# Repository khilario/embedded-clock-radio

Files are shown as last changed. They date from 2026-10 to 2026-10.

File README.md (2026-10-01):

# Embedded Clock Radio

A custom embedded clock radio built around the Raspberry Pi Pico W, featuring FM radio playback, alarm functionality, an OLED user interface, rotary encoder controls, a custom 4-layer PCB, and a 3D-printed enclosure.

This project was completed for **ECE 299 at the University of Victoria** as a two-person engineering design project.

<p align="center">
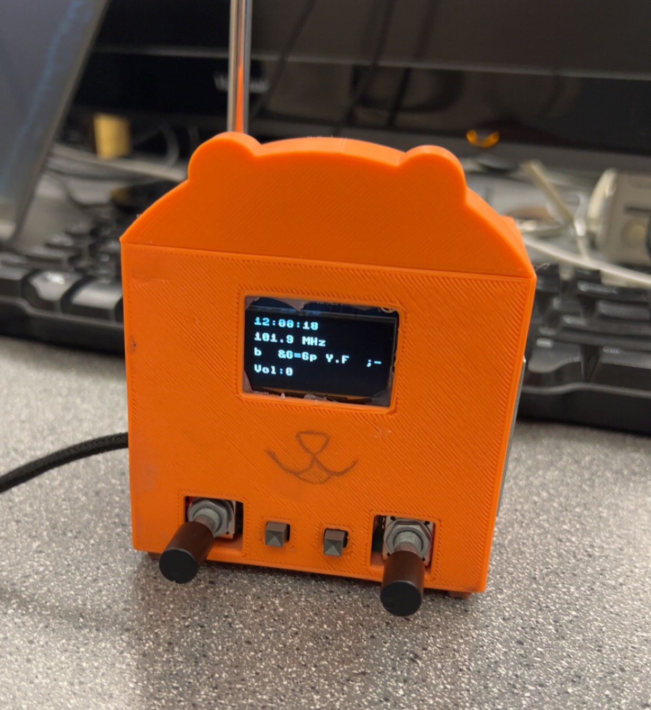
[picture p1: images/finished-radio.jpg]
Finished Embedded Clock Radio
  
</p>

## Project Overview

The goal of this project was to design and build a fully integrated clock radio using a Raspberry Pi Pico W running MicroPython.

The system combines embedded firmware, analog audio circuitry, PCB design, user-interface development, and mechanical enclosure design into a single working device.

### Key Features

- FM radio tuning and playback
- 12-hour and 24-hour time display
- Configurable alarm functionality
- Snooze and alarm cancellation
- OLED user interface
- Rotary encoder control for volume and radio tuning
- RDS station and track information
- Custom 4-layer PCB
- LM386-based audio amplification
- Custom 3D-printed enclosure

## Hardware

The clock radio is built around the following components:

- Raspberry Pi Pico W (RP2040)
- RDA5807M FM radio receiver
- SSD1306 1.3" OLED display
- LM386 audio amplifier
- 2 W, 8 Ω speaker
- 2 rotary encoders
- Push buttons
- Custom 4-layer PCB

## Communication Interfaces

- **I²C** — communication with the RDA5807M FM receiver
- **SPI** — communication with the SSD1306 OLED display
- **GPIO** — rotary encoders and push-button inputs

## PCB Design

The PCB was designed in **KiCad** as a compact 4-layer board.

The design separated power, ground, digital control, and analog audio signals across multiple layers to improve routing and reduce interference.

The board was fabricated externally and manually assembled using both SMD and through-hole components.

### PCB

<p align="center">
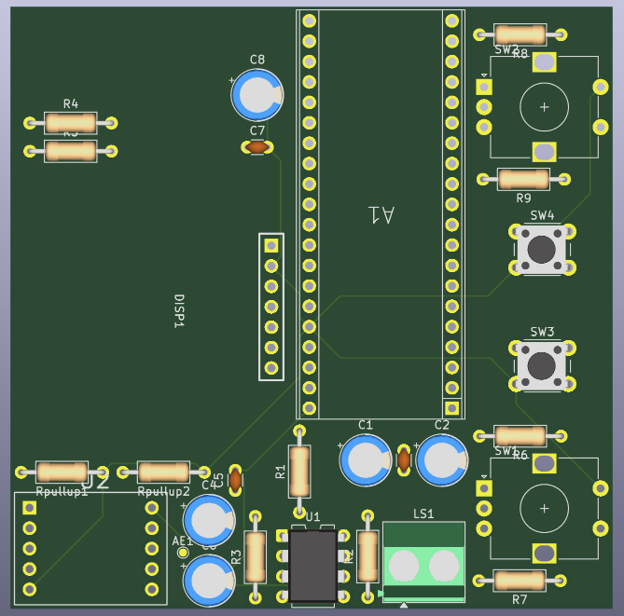
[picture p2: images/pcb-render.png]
KiCad PCB 3D Render
  
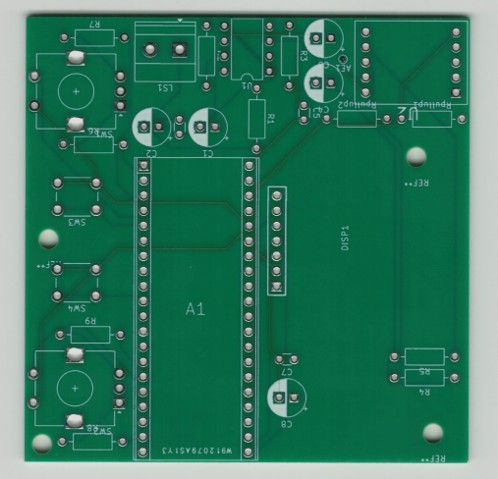
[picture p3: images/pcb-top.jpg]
Fabricated PCB
  
</p>

### Circuit Schematic

<p align="center">
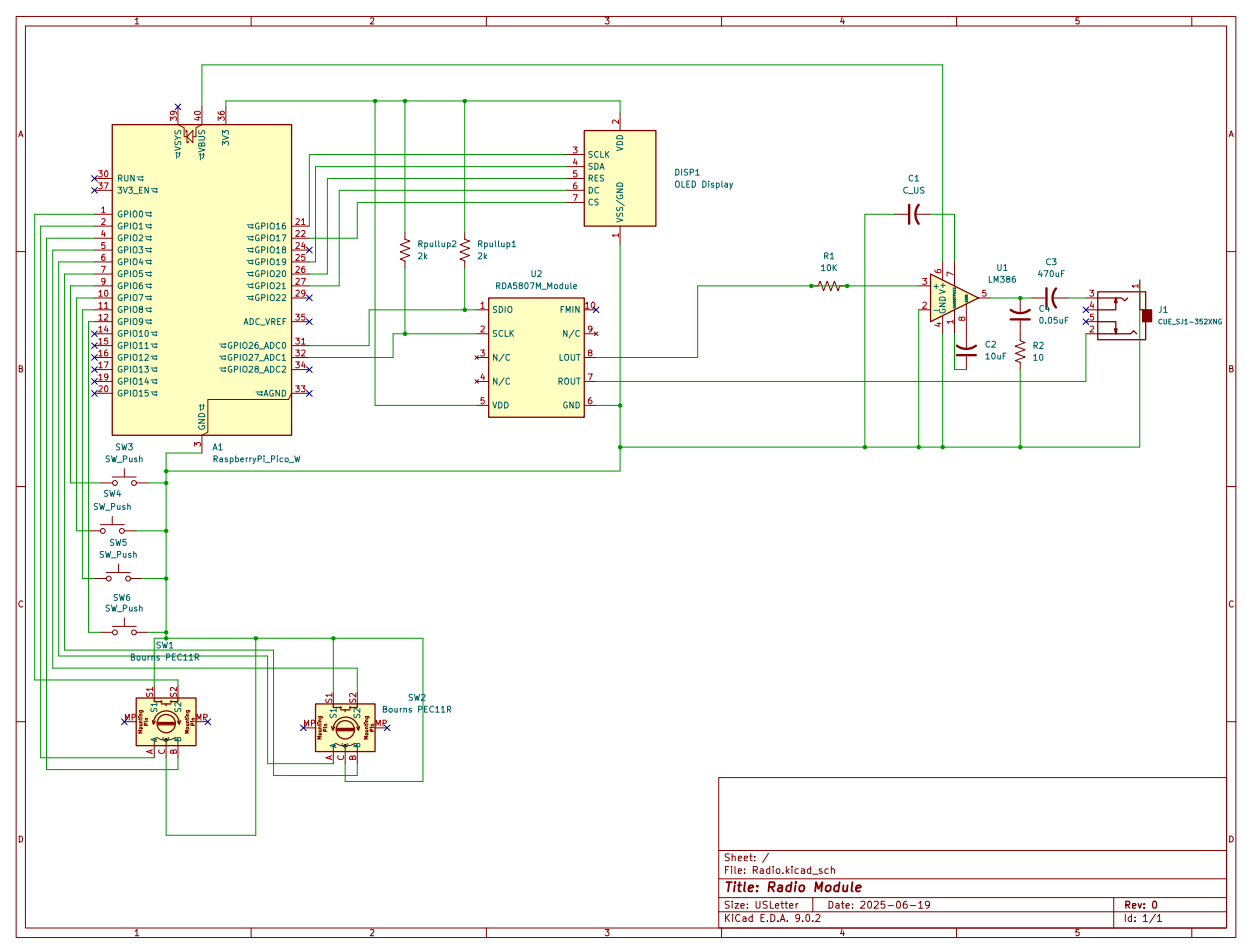
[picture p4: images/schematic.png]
Clock Radio Circuit Schematic
  
</p>

### PCB Highlights

- 4-layer PCB layout
- Dedicated power and ground routing
- Mixed analog and digital circuitry
- RDA5807M radio integration
- LM386 audio amplifier stage
- Raspberry Pi Pico W integration
- Test points for debugging and validation

## Firmware

The system firmware was written in **MicroPython** and runs on the Raspberry Pi Pico W.

The firmware handles:

- Real-time clock functionality
- FM radio tuning
- Volume control
- Alarm configuration
- Snooze and cancellation
- Rotary encoder input
- OLED menu navigation
- RDS station and song information

The main firmware and supporting drivers are located in the [`firmware`](firmware) directory.

## Testing and Debugging

The design was initially prototyped and validated on a breadboard before being transferred to the custom PCB.

Testing and debugging included:

- Oscilloscope measurements
- Power-supply noise reduction
- Rotary encoder debouncing
- FM tuning and audio testing
- OLED display troubleshooting
- PCB rework after identifying display pin-mapping issues
- Full hardware and firmware integration testing

## Enclosure Design

The enclosure was designed in **SolidWorks** and 3D printed in PLA.

<p align="center">
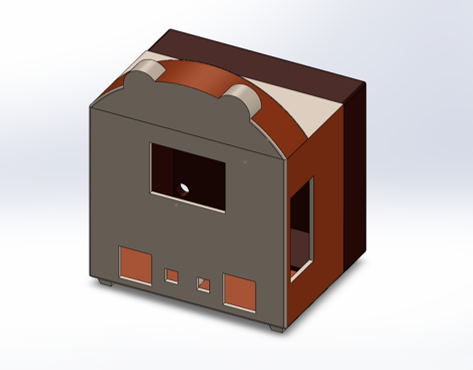
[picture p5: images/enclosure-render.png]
SolidWorks Clock Radio Enclosure
  
</p>

The enclosure includes:

- OLED display opening
- Rotary encoder controls
- Speaker opening
- USB/power access
- Internal PCB mounting features
- Animal-themed exterior design

Design files are available in the [`enclosure`](enclosure) directory.

## Repository Structure

```text
embedded-clock-radio/
├── firmware/
│   ├── radio.py
│   ├── ssd1306.py
│   ├── rotary.py
│   ├── rotary_irq_rp2.py
│   └── development/
├── hardware/
│   ├── kicad/
│   └── gerbers/
├── enclosure/
├── images/
├── docs/
│   └── ECE299_Final_Report.pdf
└── README.md
```

## My Contributions

This project was completed by a two-person team.
My primary contributions included:

- Leading the schematic and PCB design in KiCad
- Designing the 4-layer PCB layout
- Testing FM tuning, audio output, and OLED feedback
- Designing the enclosure in SolidWorks
- Developing UI functionality for time setting and display formatting
- Hardware debugging, testing, and final system integration

Technologies Used

- KiCad
- SolidWorks
- MicroPython
- Raspberry Pi Pico W
- RP2040
- I²C
- SPI
- Soldering
- Oscilloscope testing
- PCB design
- 3D printing

## Documentation

The full project report contains additional details on the design process, PCB development, testing, and project decisions.

[View the ECE 299 Final Report](docs/ECE299_Final_Report.pdf)

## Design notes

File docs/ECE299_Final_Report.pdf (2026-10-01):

# Animal-Themed Clock Radio ECE 299 Final Report

University of Victoria
Group ID: G11
Garrett Ma - V00976948
Karl Hilario – V00983970

## Table of Contents

## Acknowledgement

We acknowledge with respect the Lekwungen peoples on whose traditional territory the university stands and the Songhees, Esquimalt and WSÁNEĆ peoples whose historical relationships with the land continue to this day.

## Abstract

This project presents the design and implementation of an animal themed clock radio. The clock radio should be able to play the radio, show the time and other crucial clock information, and be user friendly. The clock radio will be controlled by Raspberry Pi Pico W using the MicroPython programming language and control other components using the SPI protocol.
A design for our PCB was breadboarded, drawn out and routed in KiCad, then manufactured at a facility. In our case the PCB got a little cramped, so we used a 4-layer PCB design which aided in routing simplicity. Some mistakes in the schematic and component placement caused us to rework our board but worked flawlessly afterwards. The housing was designed in Solidworks, had a simple and functional design, and was complimented with a cute cat design.
Overall, the core functionality of the radio was completed for both hardware and software. Some PCB rework was required, to get the screen to work and oriented in the correct way. Additionally, the reception in the lab was bad and our radio data system (RDS) information would not load correctly.

## List of Tables

Table 1: Table showing steps and roles in accomplishing project expectations | 9
Table 2: Table showing the costs of each component | 11

## List of Figures

Figure 1: Circuit Schematic | 10
Figure 2: Top side of PCB | 12
Figure 3: Bottom side of PCB | 13
Figure 4: 3D view of populated PCB | 14
Figure 5: 3D model of enclosure design | 16
Figure 6: Drawing of enclosure design | 16
Figure 7: Picture of enclosure in slicer which shows standoffs that weren’t printed | 17

## Project Goal

The goal of this project is to develop and manufacture a clock radio controlled by a Raspberry Pi Pico W programmed with MicroPython. The alarm shall integrate core functionality like, time tracking in 12 and 24 hour time, alarm, and radio. All this information will be displayed on a 1.3” OLED SPI-based display, audio will be played through an integrated speaker, and 2 buttons and 2 rotary encoders will be included to interact with the clock radio.
The clock radio will be designed by the student and some components will be sent for manufacturing. We will design a PCB which will hold and connect all the components. A housing will also be designed with an animal theme without compromising on the functionality of the radio. In the end, the completed radio will be demonstrated and a conversation on the design and ideas behind the project will be shown.

## Constraints

There are some constraints on the project to encourage creativity and test knowledge. Since the project cannot be a breadboard project, money will have to be spent on components, PCB manufacturing, and the housing. Therefore, our goal is to minimize cost and mistakes. Additionally, we are limited to one Raspberry Pi Pico W and it must control all the components and communications and programmed with MicroPython.

## Project Expectations

1. Design and develop a prototype of an animal themed clock-radio that has the following functionalities.
Clock functionalities
- Set/Edit time through a user interface
- Set/Edit alarm time through a user interface
- Display time in 12-hour/24-hour format as desired by the user
- Trigger alarm as set by the user
- Snooze alarm & turn-off alarm through a user interface Radio functionalities
- Tune to at least one FM radio channel through a user interface
- Play radio output on to a speaker
- Volume control of audio output through a user interface
- Display radio channel info to the user
2. Design a two-layer printed circuit board (PCB) for the clock-radio and get it manufactured from a commercial PCB manufacturer.
3. Solder the components on to the manufactured PCB.
4. Design and manufacture an animal themed enclosure for the clock-radio.
5. Present the clock-radio packaged in an animal themed enclosure by the last week of labs.

## Design Choices

Clock Functionalities
- Set/Edit Time through UI
Design: Time was managed using the onboard RTC module (machine.RTC) from the RP2040. Two rotary encoders with push-button functionality allow users to set hours, minutes, and alarm time via menu-based UI.
Justification: The Raspberry Pi Pico W supports flexible GPIO assignment and RTC libraries in MicroPython. Rotary encoders with built-in button presses simplify interface logic while reducing hardware clutter.
- Alarm and Snooze
Design: Alarms were handled by checking the current time each second. If matched, a snooze/cancel OLED interface appears.

Justification: A state-driven alarm logic was implemented in radio.py. Alarms trigger audio playback through the FM module with the volume pre-set to 15. Snooze delays are tracked using time.time().
- 12/24 Hour Format Switching
Design: A toggle stored in is_24_hour_format determines how the time is rendered on the OLED screen.
Justification: Using MicroPython’s datetime formatting tools, this toggle allows flexible display formatting without increasing computational complexity.
Radio Functionalities
- FM Tuning and Playback
Design: The RDA5807M FM chip is controlled via I2C using rotary encoder input. Frequency values are mapped to 10-bit channel values per the datasheet. Justification: RDA5807M supports fast tuning via I2C and has built-in mute, bass boost, and stereo options. Rotary encoder input is intuitive and allows for rapid tuning increments.
- Volume Control
Design: One encoder adjusts the volume from 0 to 15. The corresponding register (0x05) is updated via I2C with each change.
Justification: Volume is handled entirely in the digital domain, reducing component count and avoiding analog noise pickup.
- RDS Display
Design: Station metadata (name, song info) is decoded via the GetRDS() function in radio.py, parsed into scrollable text and shown on the OLED.
Justification: RDA5807M supports RDS standard decoding through registers that provide 4-block group messages. The implementation handles character pairing, filtering, and display buffering.
OLED Display and UI
- OLED (SSD1306 SPI)
Design: Display initialized using ssd1306.py with SPI interface to show current time, frequency, volume, RDS data, and alarm prompts.
Justification: SPI offers faster transfer and fewer glitches compared to I2C. The

SSD1306 controller supports page addressing and contrast adjustment, handled through command macros in the driver.
- Input Devices
Design: Two rotary encoders are used—one for volume and one for frequency—with both having push-button functionality. Two additional physical push buttons are used for alarm and time format toggle.
Justification: Minimizing input hardware while maximizing function was a design goal. Rotary encoders with built-in buttons enabled 4 total inputs using only 2 encoders and 2 extra buttons.
PCB Design and Manufacturing
- 4-layer PCB
Design: Designed in KiCad with proper power/ground planes for analog and digital domains. High-speed I2C lines, speaker traces, and Pico W were routed on different layers.
Justification: A 4-layer board improves signal integrity, reduces EMI, and allows better separation between digital control and analog audio. This choice also facilitated a compact layout within the enclosure.
- Component Soldering
Design: A combination of SMD and through-hole components were manually soldered. Justification: Through-hole parts allowed reliable mounting for Pico W and connectors. SMD resistors and caps helped with compact layout. PCB assembly was validated with test points and oscilloscope probing.
Enclosure and Packaging
- 3D-Printed Animal-Themed Housing
Design: Enclosure modelled in SolidWorks and printed in PLA with snap-fit supports for the PCB and faceplate openings for UI controls. Cat-themed housing was designed. Justification: PLA is lightweight and thermally stable for electronics. SolidWorks enabled precise fit and integration of design aesthetics with functional constraints.

## Project Planning

To complete the animal-themed clock radio within the project timeline, we outlined the steps needed to meet each of the course expectations and coordinated team roles accordingly. While we initially divided tasks between hardware and software, in practice, both team members worked collaboratively on all aspects of the project—including debugging, testing, and integration.
The table below summarizes how we addressed each project expectation, the major tasks involved, and the shared roles of both team members in completing them.
Team Roles and Responsibilities
Project Expectation | Steps Taken | Team Roles
1. Functional Clock System | • Designed menu-based UI for setting time and alarm • Implemented 12/24-hour formatting toggle • Alarm and snooze logic programmed and tested | - Garrett developed alarm trigger and snooze code - Karl created UI menus for time setting and formatting
2. Functional FM Radio | • Interfaced RDA5807M via I2C for tuning and RDS • Connected to LM386 amplifier and speaker • Volume and channel control through encoders | - Garrett handled radio driver and I2C integration - Karl tested tuning, audio output, and OLED feedback
3. 4-layer PCB Design & Manufacturing | • Designed schematic and layout in KiCad • Added power, analog, and digital signal traces across four layers • Sent for fabrication and soldered components | - Karl led schematic/PCB design - Garrett assisted with debugging and soldering components

4. Animal-Themed Enclosure | • Modelled in SolidWorks with cutouts for screen, buttons, and speaker • 3D printed and assembled enclosure with mounted board and display | - Karl designed the enclosure - Garrett printed the enclosure and tested PCB/enclosure alignment and mounting
5. Full Integration & Packaging | • Assembled all components • Final OLED UI implemented • Validated alarm, radio, and display functionality inside enclosure | - Both members tested and validated features jointly - UI polish and bug fixing done collaboratively

Table 1: Table showing steps and roles in accomplishing project expectations
Execution vs. Original Plan
We followed the original project milestone plan closely, with all major deliverables completed on schedule. These include:
- Breadboard testing and validation of all subsystems
- Completion and assembly of a custom 4-layer PCB
- Final 3D-printed themed enclosure
- Integrated software combining timekeeping, FM radio, alarm, and UI display
While the roles were originally divided by hardware and software focus, in practice both team members worked collaboratively on all parts of the project. Tasks such as debugging, integration, and testing were conducted together. This teamwork helped ensure rapid troubleshooting and polished results.

## Circuit Design and Schematic

Below in figure 1 is the circuit schematic drawn in KiCad. Each of these components were iteratively added after each tutorial after learning how each piece worked. Then after breadboarding everything together we would add more components and wires onto the schematic after testing.
Two big points are the resistors and capacitors we added to debounce and reduce noise of certain components. Firstly, power from a USB is often noisy and sometimes not grounded very well. Adding two capacitors from the 3.3v and 5v rails in parallel with ground help smooth out the output of the power leading to a better sounding speaker and better performing op-amp. Secondly, we had issues with debouncing the rotary encoders and it would randomly output different values then the direction we were turning it. Adding a resistor in series helped limit current which helps reduce the transient spikes that the GPIO pin would read. Additionally, software tricks like adding a finite state machine (FSM) helped ensure we didn’t have unwanted values. All of this led to the actual 4-layer PCB found in figure 2.

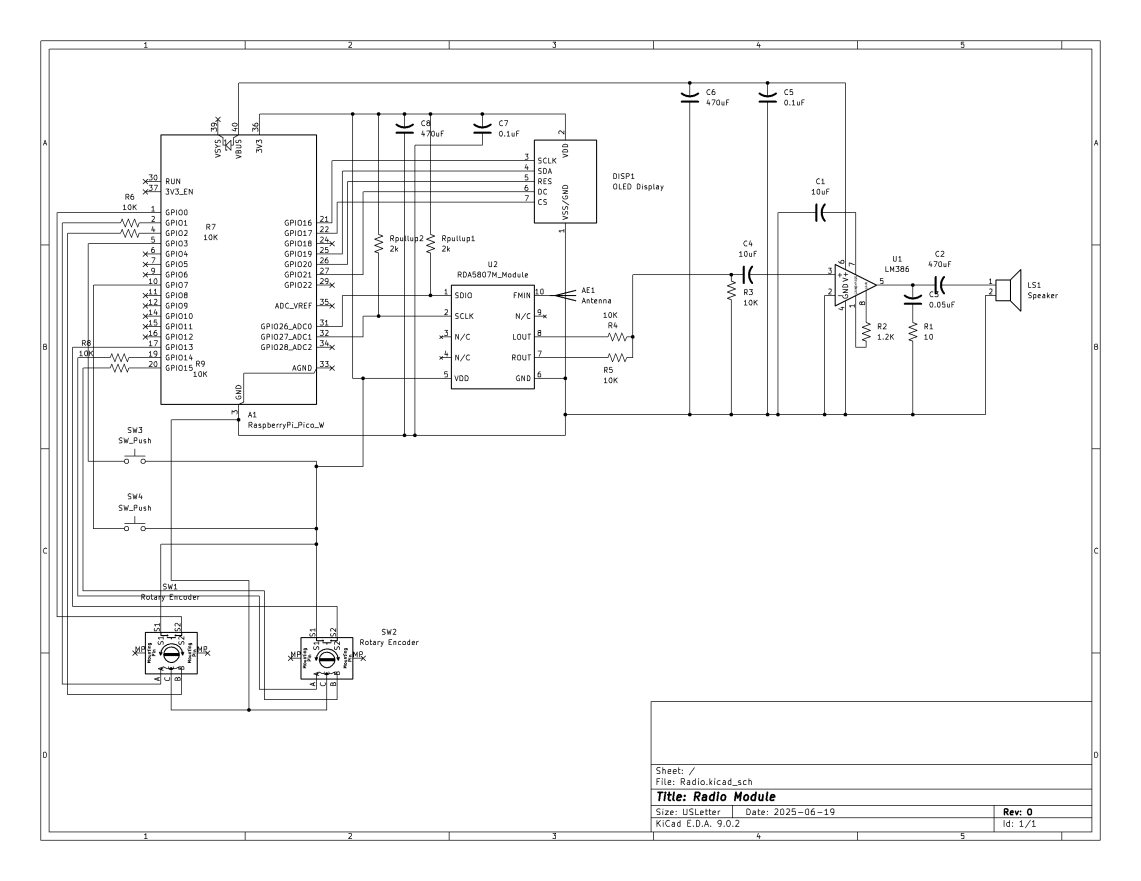
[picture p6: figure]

Figure 1: Circuit Schematic

## Bill of Materials

The table below outlines the Bill of Materials (BOM), listing all major components used in the final design along with their specifications, quantities, and sources.

Label in schematic | Component Description | Cost/unit quantity | Source of cost information
A1 | Raspberry Pico W | $10.00 x 1 | ECE 299 Parts List with price info
PCB | Manufactured PCB | $10.00 x 5 | PCBWay invoice
U1 | LM386N-4 Audio Amplifier | $1.50 x 1 | ECE 299 Parts List with price info
U2 | RDA5807M on Through-hole PCB | $2.00 x 1 | ECE 299 Parts List with price info
DISP1 | 1.3” OLED Display SPI | $4.00 x 1 | ECE 299 Parts List with price info
LS1 | Speaker 2W 8Ω | $4.00 x 1 | ECE 299 Parts List with price info
SW1, SW2 | Rotary Encoder | $1.00 x 2 | ECE 299 Parts List with price info
SW3, SW4 | Pushbutton Microswitch PCB | $0.25 x 2 | ECE 299 Parts List with price info
R1, …, R8, Rpullup1, Rpullup2 | Resistors | Free | ECE 299 Parts List with price info
C1, …, C8 | Capacitors | Free | ECE 299 Parts List with price info

Table 2: Table showing the costs of each component

## Printed Circuit Board

In the 3 pictures below are the empty PCB and a fully populated PCB. Like above, we had used a 4-layer PCB to separate all the signals, power and ground into different layers and kept the PCB very compact. Each side is 75mm, giving us an area of 5,625 mm² which is above the 3000mm² expectation.
A few problems we ran into after ordering the PCB, lots requiring ingenuity and handywork. We realized first that the orientation of the Pico had the USB port facing inwards meaning that any of the components in that direction had to be mounted on the back (C1, C2, etc.) This led to us realizing that we should have just put everything on the back and only left the screen and buttons on the front which would have let us have it nicely pressed up against the front of the housing rather than it just laying there. After assembling the board, the screen wouldn’t turn on and it was upside down. Looking at the schematic, all of the OLED pins were off by one and as a result we had to rework the board. After reworking the board with longer wires which gave us room to flip the display it finally worked.

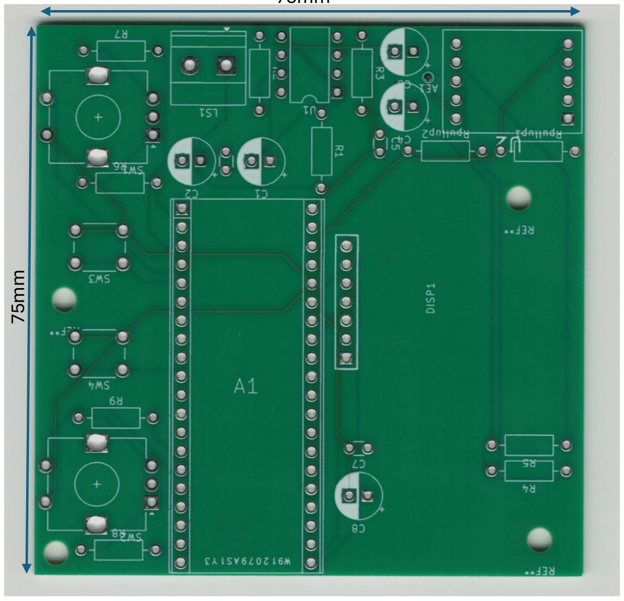
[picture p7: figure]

Figure 2: Top side of PCB

75mm

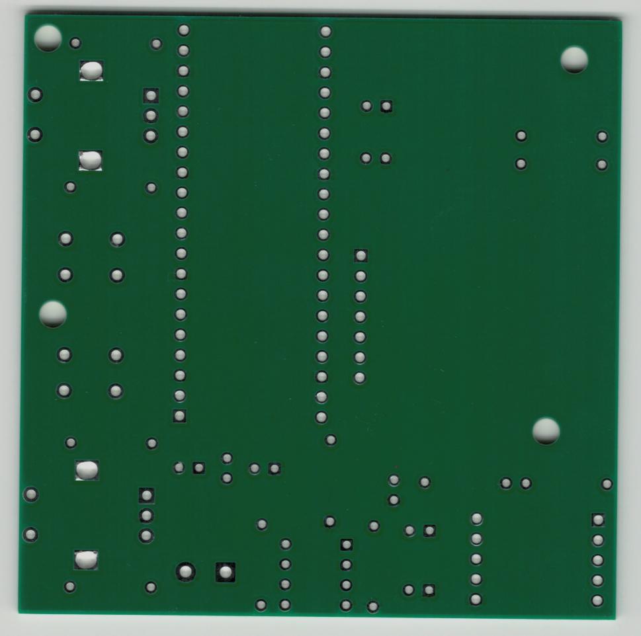
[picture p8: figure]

Figure 3: Bottom side of PCB

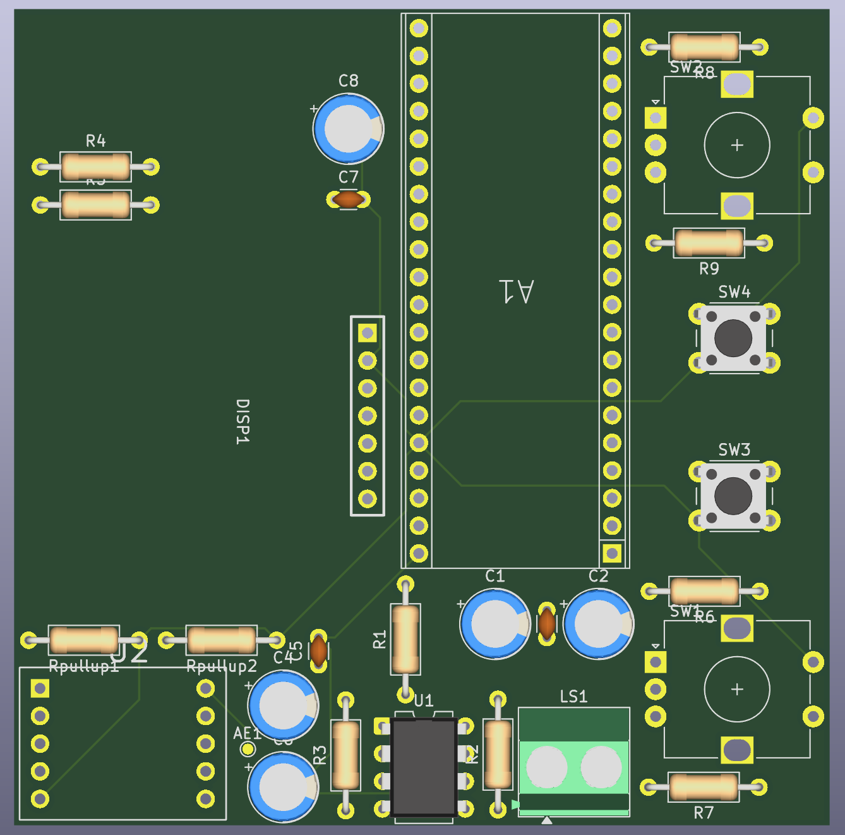
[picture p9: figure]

Figure 4: 3D view of populated PCB

## Enclosure Design

The enclosure was modelled using SolidWorks to match the project’s animal-themed aesthetic while maintaining functional requirements for component access and airflow. The design features precise cutouts for the OLED display, rotary encoders, speaker grill, and USB/power access to the Raspberry Pi Pico W.
The enclosure consists of two interlocking halves that were 3D printed using PLA filament. PLA was chosen for its ease of printing, rigidity, and thermal stability, which makes it ideal for electronic housings. Tabs and standoffs were integrated into the model to securely hold the custom PCB in place and align the display with the outer face.
The front panel includes the OLED window and symmetrical placement of the encoders and speaker, providing a clean and intuitive user interface (see Fig. 5). The rear section allows routing for power and audio connections while enclosing the LM386 amplifier and speaker mount (see Fig. 6).
Standoffs and mounting tabs were integrated into the SolidWorks model to support the PCB and hold the display flush with the outer surface. However, as shown in Fig. 7, these standoffs were present in the slicer preview but were not printed in the final version due to support and clearance issues. The enclosure still functioned correctly without them, as the PCB fit snugly inside the shell and was stabilized using press-fit tolerances and hot glue reinforcement where needed.

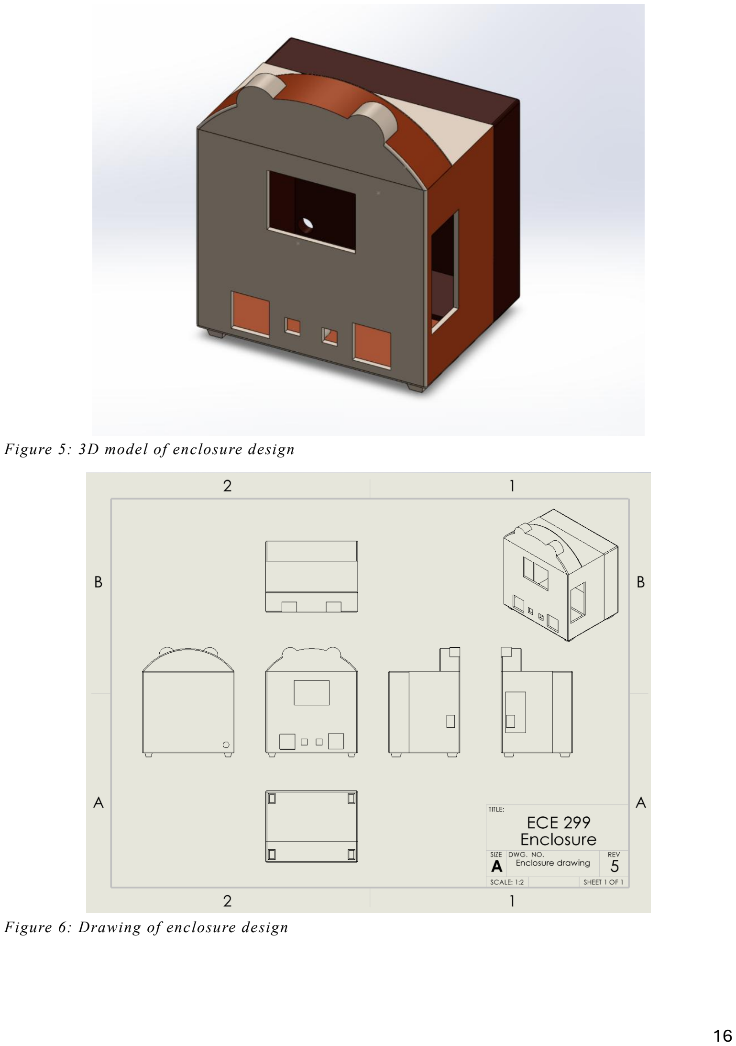
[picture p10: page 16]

Figure 5: 3D model of enclosure design

Figure 6: Drawing of enclosure design

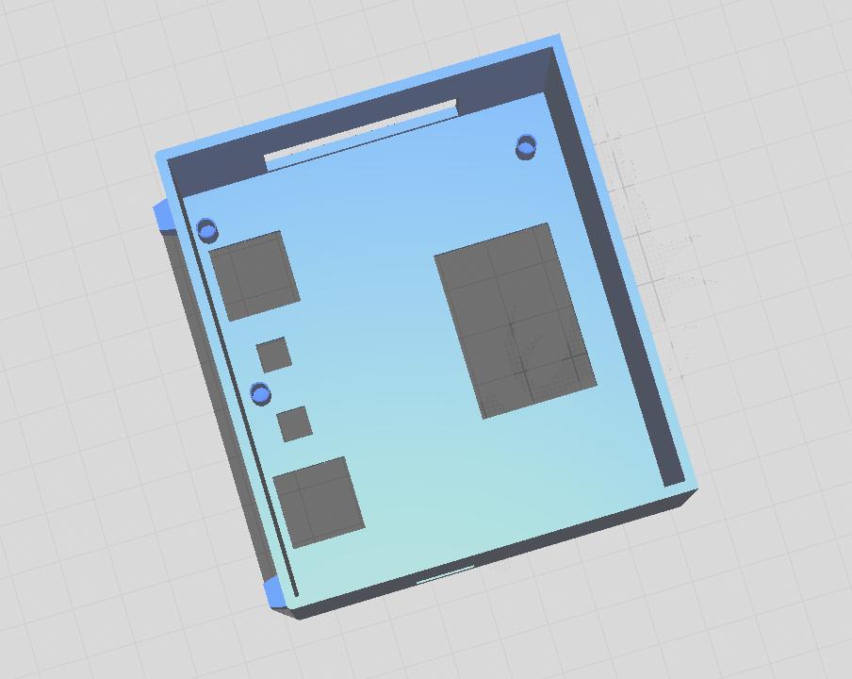
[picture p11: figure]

Figure 7: Picture of enclosure in slicer which shows standoffs that weren’t printed

## Testing & Validation

A video to the full testing of the hardware and software can be found here. (https://drive.google.com/file/d/1bFmbeju5GJj66Gmw7ynh2niurC5ezluY/view?usp=sharing)

## Code of Ethics (EGBC)

During the development of the clock radio, we took appropriate precautions and followed EGBC’s Code of Ethics [X]. This final report shows our development process which shows that we are practicing in fields where training will make us professionally competent. Additionally, this final report provides accurate information with respect to our qualifications and experience and that we are ensuring our safety first by working on a breadboard first ensure our clock pulls a reasonable amount of power and not damage property. These are just some of the relevant Code of Ethics we followed throughout the development of the clock radio.

## Conclusion & Recommendations

The development of the clock radio in this project was a fun project which allowed us to apply fundamental engineering principles and apply our knowledge from previous courses. We got to learn how to use industry standard tools such as KiCAD and SolidWorks which we can use in our personal projects or future jobs/classes. We also got to apply our coding knowledge, circuitry, and planning skills which aided in task completion. The issues we faced during the project could have been easily avoided with additional time to review our PCB or having extra time to order a new PCB. Finally, if we had more thoroughly reviewed the rubric we would have seen that the radio was not suffice and implemented the piezo buzzer to meet the expectations. This project gave us valuable hands-on experience developing, troubleshooting, and project management.

Recommendations:
If we were to pass on any advice to future students based on our experience:
1. Read the rubric in full, list components you know you will need from the 5 tutorial labs and from the rubric to make sure you hit all expectations.
2. Send the PCB for manufacturing early. Double, triple check your schematic to ensure nothing was accidentally misplaced to reduce any reworks to your PCB which minimizes costs and potential reworking mistakes.
3. Make use of the breadboard. It made troubleshooting much easier as we already knew our design worked even before sending our PCB for production.

## References

[1] Engineers and Geoscientists British Columbia, "Code of Ethics," [Online]. Available: https://www.egbc.ca/Complaints-Discipline/Code-of-Ethics/Code-of-Ethics
[2] Raspberry Pi Foundation, “Raspberry Pi Pico W Datasheet,” [Online]. Available: https://datasheets.raspberrypi.com/picow/pico-w-datasheet.pdf
[3] Texas Instruments, “LM386 Low Voltage Audio Power Amplifier,” [Online]. Available: https://www.ti.com/lit/ds/symlink/lm386.pdf
[4] ECE 299 Course Team, “ECE 299 Lab Manual,” University of Victoria, 2024. [Online]. Available on Brightspace.
[5] Adafruit, “SSD1306 OLED Display Driver,” [Online]. Available: https://cdn-shop.adafruit.com/datasheets/SSD1306.pdf
[6] “Getting Started in KiCad,” University of Victoria, 2024.
[7] “Getting Started with SolidWorks,” University of Victoria, 2024.
[8] Analog Devices, “Basics of I2C Protocol,” [Online]. Available: https://www.analog.com/media/en/technical-documentation/application-notes/AN686.pdf
[9] RDA Microelectronics, “RDA5807M FM Receiver IC – Programming Guide,” [Online]. Available: https://datasheet.lcsc.com/lcsc/1811141540_RDA-Microelectronics-RDA5807M_C27381.pdf

## Appendix A

A link to our GitHub repository with our code and diagrams can be found here. (https://github.com/garrettma03/ECE-299-Radio)

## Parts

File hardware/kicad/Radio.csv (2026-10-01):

Id | Designator | Footprint | Quantity | Designation | Supplier and ref
1 | C2,C6,C8 | CP_Radial_D6.3mm_P2.50mm | 3 | 470uF
2 | LS1 | TerminalBlock_Phoenix_MKDS-1,5-2_1x02_P5.00mm_Horizontal | 1 | Speaker
3 | Rpullup1,Rpullup2 | R_Axial_DIN0207_L6.3mm_D2.5mm_P10.16mm_Horizontal | 2 | 2k
4 | R4,R5,R6,R9,R3,R7,R8 | R_Axial_DIN0207_L6.3mm_D2.5mm_P10.16mm_Horizontal | 7 | 10K
5 | C4,C1 | CP_Radial_D6.3mm_P2.50mm | 2 | 10uF
6 | R2 | R_Axial_DIN0207_L6.3mm_D2.5mm_P10.16mm_Horizontal | 1 | 1.2K
7 | SW3,SW4 | SW_PUSH_6mm | 2 | SW_Push
8 | R1 | R_Axial_DIN0207_L6.3mm_D2.5mm_P10.16mm_Horizontal | 1 | 10
9 | C7,C5 | C_Disc_D3.0mm_W1.6mm_P2.50mm | 2 | 0.1uF
10 | AE1 | TestPoint_Pad_D1.0mm | 1 | Antenna
11 | U2 | RDA5807M_Module_TH | 1 | RDA5807M_Module
12 | U1 | DIP-8_W7.62mm | 1 | LM386
13 | SW2,SW1 | RotaryEncoder_Alps_EC12E-Switch_Vertical_H20mm | 2 | Rotary Encoder
14 | DISP1 | OLED_Display_1.3 | 1 | OLED Display
15 | A1 | RPi_Pico_TH | 1 | RaspberryPi_Pico_W
16 | C3 | C_Disc_D3.0mm_W1.6mm_P2.50mm | 1 | 0.05uF

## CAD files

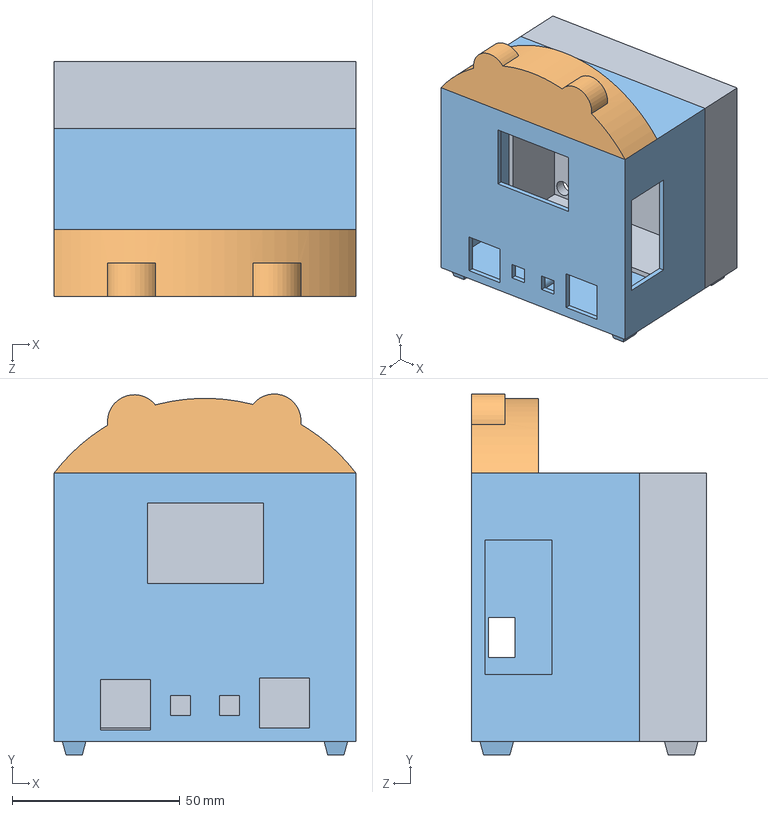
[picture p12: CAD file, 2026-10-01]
enclosure/solidworks/Housing.SLDASM
90.0 x 107.6 x 70.0 mm
Front Part
Animal
Back part

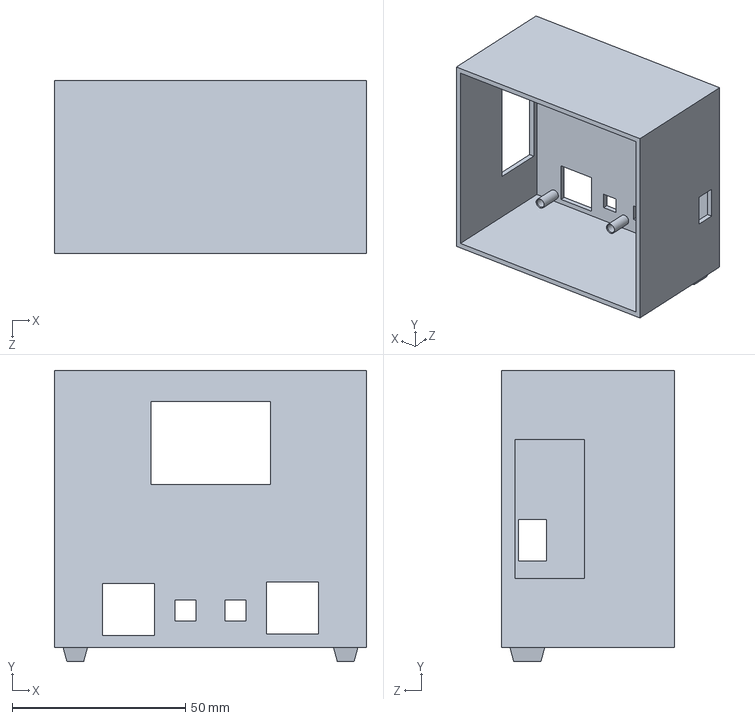
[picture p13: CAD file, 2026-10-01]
enclosure/solidworks/Front Part.SLDPRT
90.0 x 84.0 x 50.0 mm

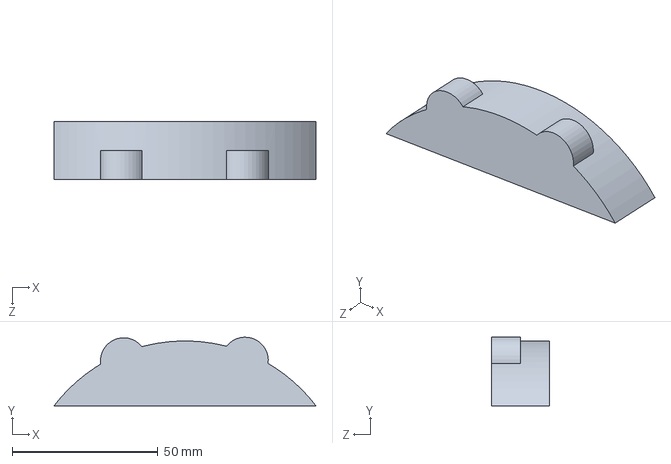
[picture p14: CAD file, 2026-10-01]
enclosure/solidworks/Animal.SLDPRT
90.0 x 23.6 x 20.0 mm

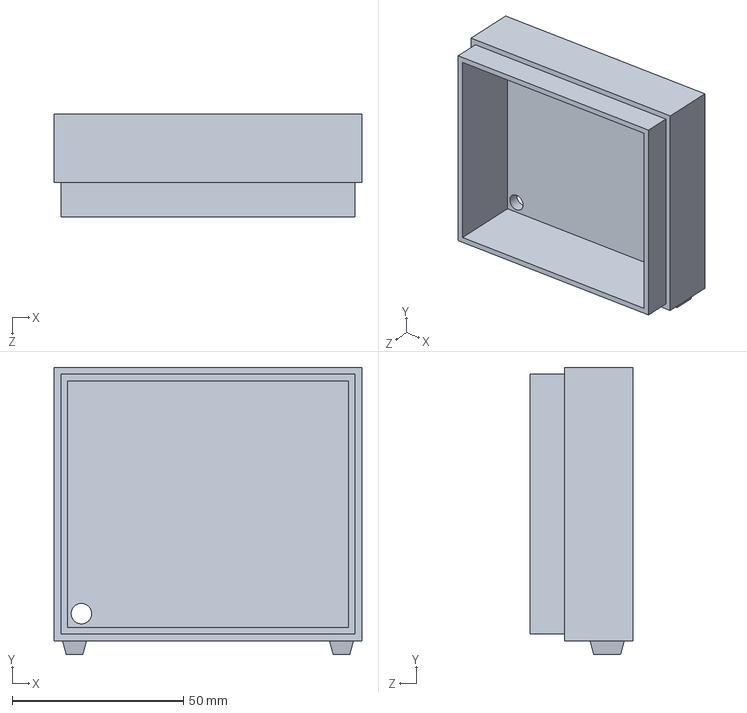
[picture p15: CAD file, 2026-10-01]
enclosure/solidworks/Back part.SLDPRT
90.0 x 84.0 x 30.0 mm

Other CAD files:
enclosure/solidworks/Enclosure drawing.SLDDRW

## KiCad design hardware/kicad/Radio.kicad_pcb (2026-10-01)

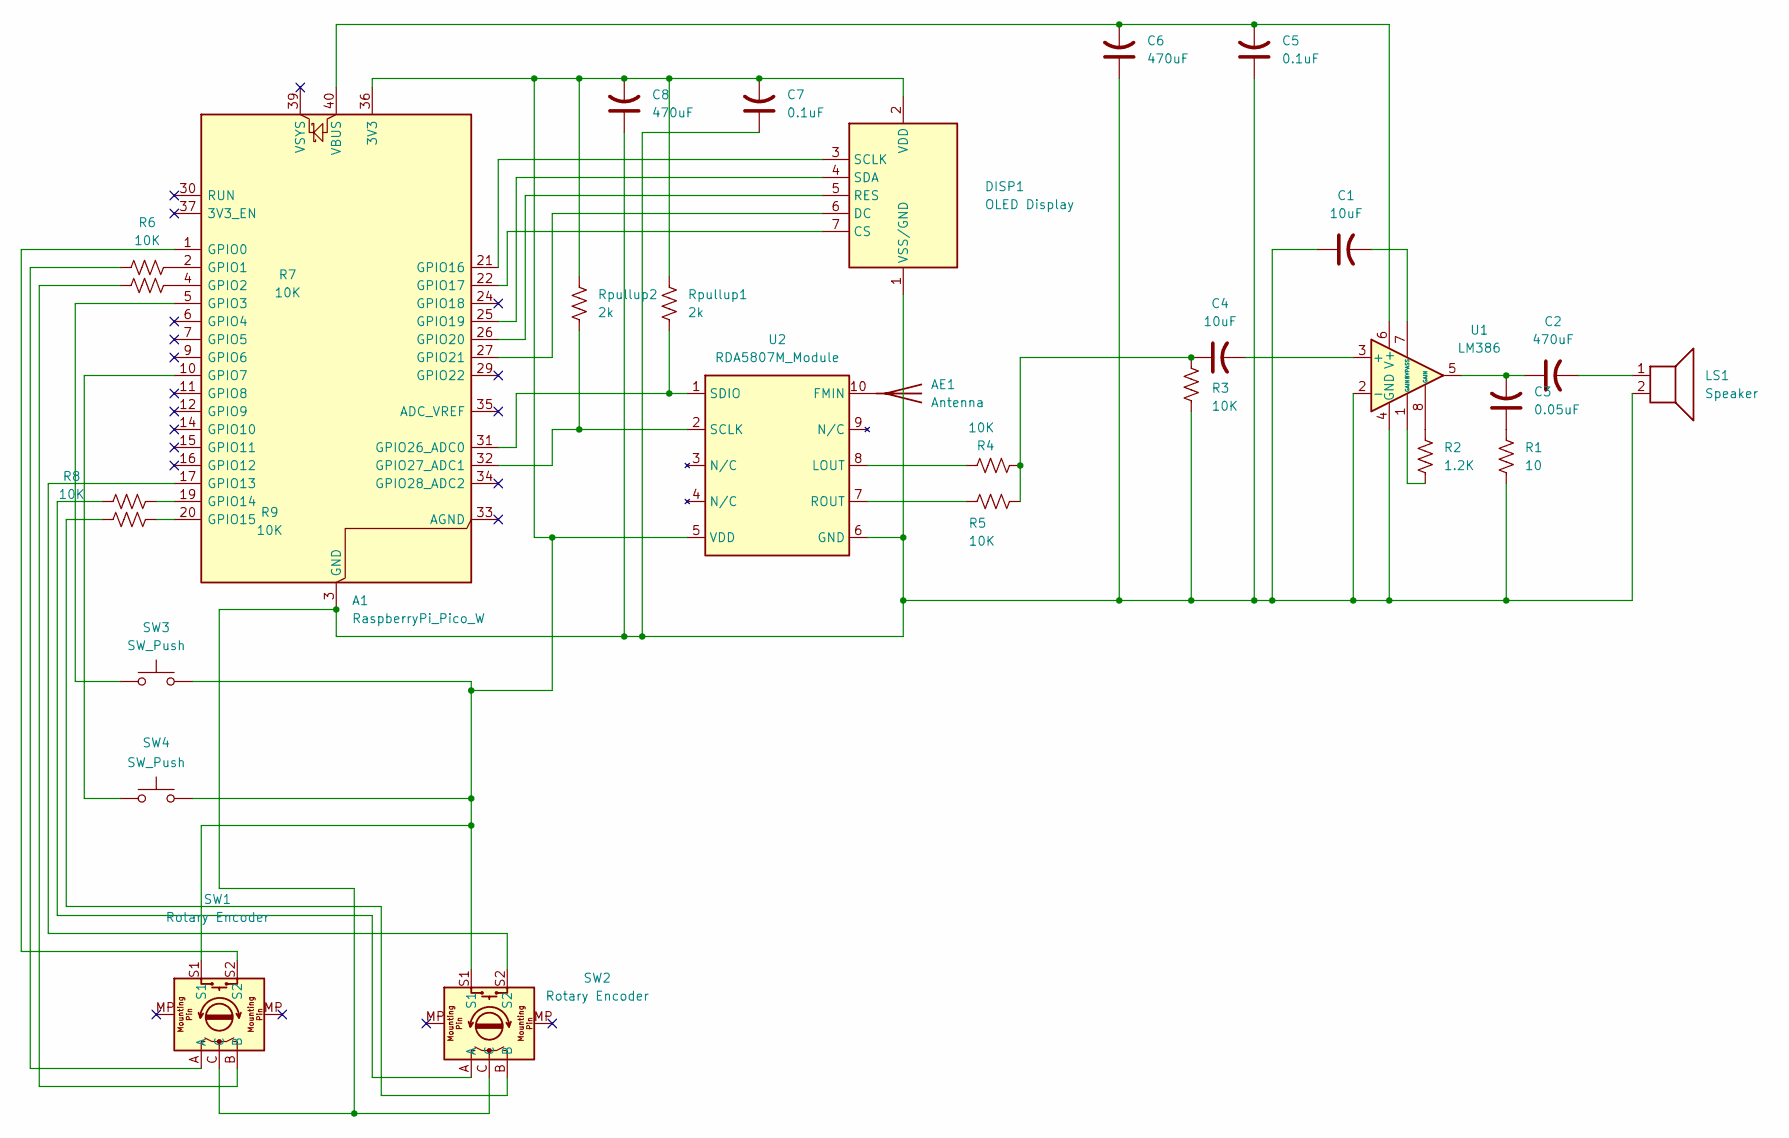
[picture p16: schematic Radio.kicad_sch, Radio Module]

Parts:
A1: RaspberryPi_Pico_W; RPi_Pico_TH
AE1: Antenna; TestPoint_Pad_D1.0mm
C1, C4: 10uF; CP_Radial_D6.3mm_P2.50mm
C2, C6, C8: 470uF; CP_Radial_D6.3mm_P2.50mm
C3: 0.05uF; C_Disc_D3.0mm_W1.6mm_P2.50mm
C5, C7: 0.1uF; C_Disc_D3.0mm_W1.6mm_P2.50mm
DISP1: OLED Display; OLED_Display_1.3
LS1: Speaker; TerminalBlock_Phoenix_MKDS-1,5-2_1x02_P5.00mm_Horizontal
R1: 10; R_Axial_DIN0207_L6.3mm_D2.5mm_P10.16mm_Horizontal
R2: 1.2K; R_Axial_DIN0207_L6.3mm_D2.5mm_P10.16mm_Horizontal
R3, R4, R5, R6, R7, R8, R9: 10K; R_Axial_DIN0207_L6.3mm_D2.5mm_P10.16mm_Horizontal
Rpullup1, Rpullup2: 2k; R_Axial_DIN0207_L6.3mm_D2.5mm_P10.16mm_Horizontal
SW1, SW2: Rotary Encoder; RotaryEncoder_Alps_EC12E-Switch_Vertical_H20mm
SW3, SW4: SW_Push; SW_PUSH_6mm
U1: LM386; DIP-8_W7.62mm
U2: RDA5807M_Module; RDA5807M_Module_TH

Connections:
unnamed: A1.36 (3V3), C7.2, C8.2, DISP1.2 (VDD), Rpullup1.1, Rpullup2.1, SW1.S1, SW2.S1, SW3.2, SW4.2, U2.5 (VDD)
unnamed: A1.1 (GPIO0), SW1.S2
unnamed: A1.2 (GPIO1), R6.2
unnamed: A1.4 (GPIO2), R7.2
unnamed: A1.5 (GPIO3), SW3.1
unnamed: A1.10 (GPIO7), SW4.1
unnamed: A1.17 (GPIO13), SW2.S2
unnamed: A1.19 (GPIO14), R8.2
unnamed: A1.20 (GPIO15), R9.2
unnamed: A1.21 (GPIO16), DISP1.3 (SCLK)
unnamed: A1.22 (GPIO17), DISP1.7 (CS)
unnamed: A1.25 (GPIO19), DISP1.4 (SDA)
unnamed: A1.26 (GPIO20), DISP1.5 (RES)
unnamed: A1.27 (GPIO21), DISP1.6 (DC)
unnamed: A1.31 (GPIO26_ADC0), Rpullup1.2, U2.1 (SDIO)
unnamed: A1.32 (GPIO27_ADC1), Rpullup2.2, U2.2 (SCLK)
unnamed: A1.40 (VBUS), C5.2, C6.2, U1.6 (V+)
unnamed: AE1.1 (A), U2.10 (FMIN)
unnamed: C2.1, C3.2, U1.5
unnamed: C2.2, LS1.1
unnamed: C3.1, R1.2
unnamed: C4.1, R3.2, R4.1, R5.2
unnamed: A1.3 (GND), A1.8 (GND), A1.13 (GND), A1.18 (GND), A1.23 (GND), A1.28 (GND), A1.38 (GND), C1.1, C5.1, C6.1, C7.1, C8.1, DISP1.1 (VSS/GND), LS1.2, R1.1, R3.1, SW1.C, SW2.C, U1.2 (-), U1.4 (GND), U2.6 (GND)
unnamed: R2.1, U1.1 (GAIN)
unnamed: R2.2, U1.8 (GAIN)
unnamed: R6.1, SW1.A
unnamed: R7.1, SW1.B
unnamed: R8.1, SW2.A
unnamed: R9.1, SW2.B
unnamed: C4.2, U1.3 (+)
unnamed: C1.2, U1.7 (BYPASS)
unnamed: R4.2, U2.8 (LOUT)
unnamed: R5.1, U2.7 (ROUT)

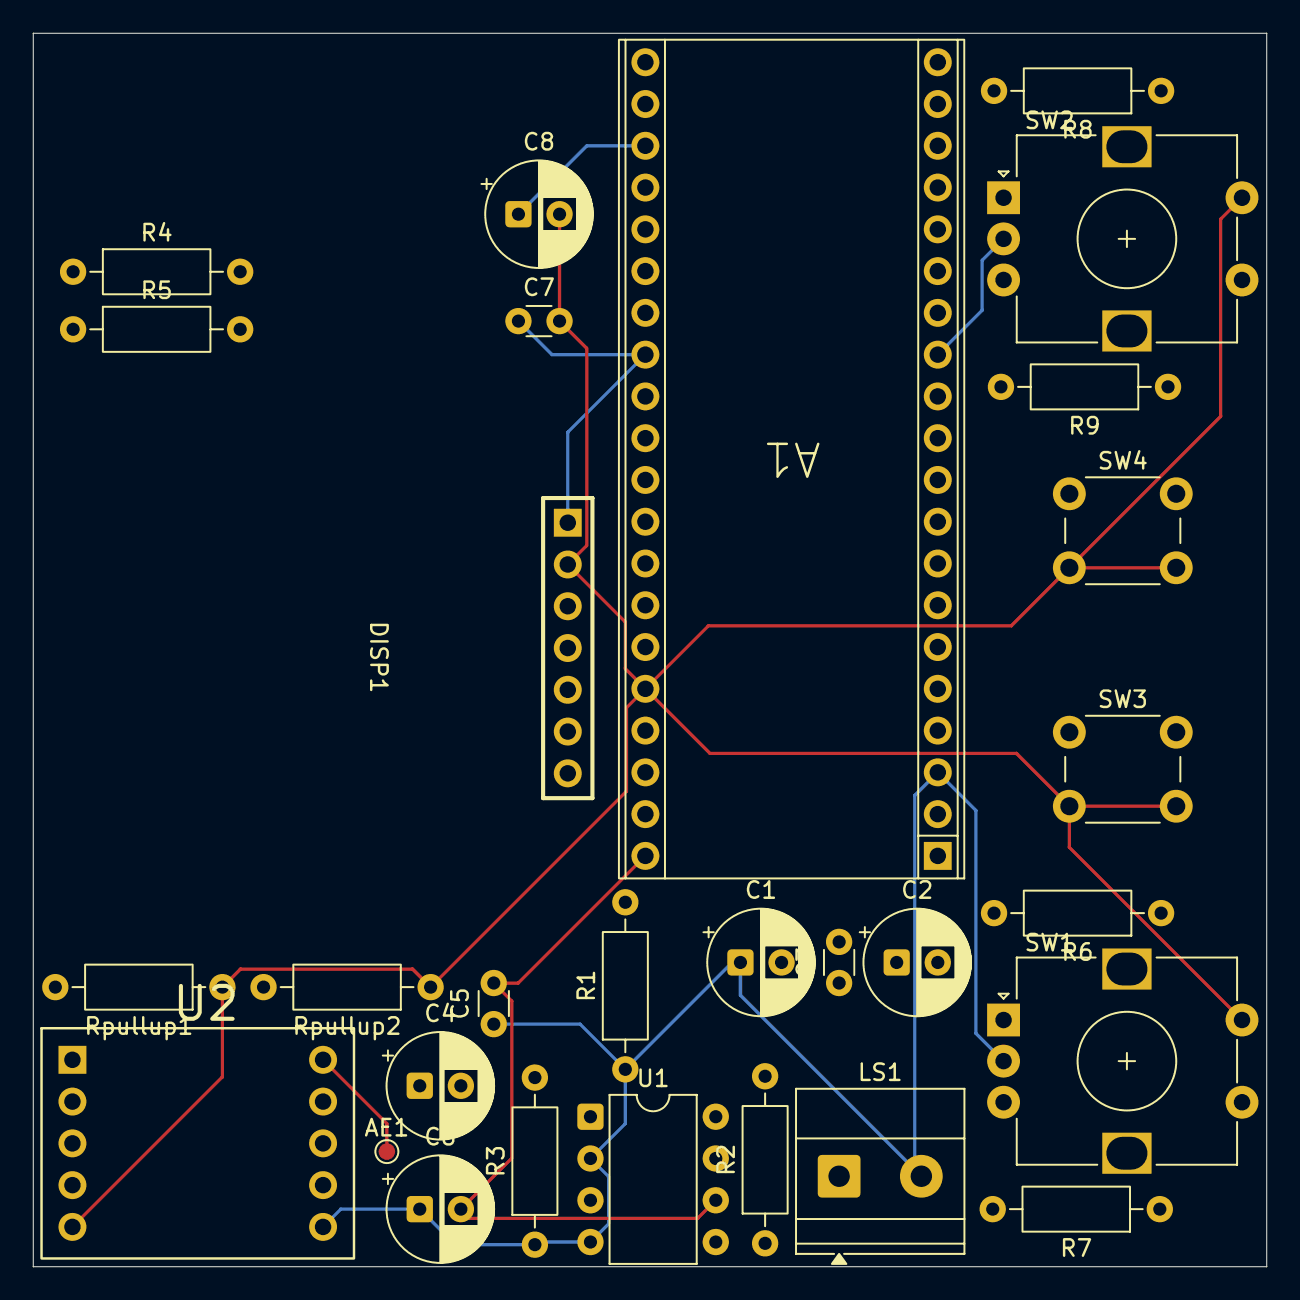
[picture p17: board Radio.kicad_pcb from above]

Board: 4 copper layers, 75.0 x 75.0 mm, 29 parts (0 on the bottom side), 33 nets.

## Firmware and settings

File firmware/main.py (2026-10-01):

from machine import Pin, I2C, SPI
import time
from rotary_irq_rp2 import RotaryIRQ
from machine import RTC
from ssd1306 import SSD1306_SPI

class Radio:

    def __init__( self, NewFrequency, NewVolume, NewMute ):

#
# set the initial values of the radio
#
        self.Volume = 1
        self.Frequency = 88
        self.Mute = False
#
# Update the values with the ones passed in the initialization code
#
        self.SetVolume( NewVolume )
        self.SetFrequency( NewFrequency )
        self.SetMute( NewMute )
        
      
# Initialize I/O pins associated with the radio's I2C interface

        self.i2c_sda = Pin(26)
        self.i2c_scl = Pin(27)

#
# I2C Device ID can be 0 or 1. It must match the wiring. 
#
# The radio is connected to device number 1 of the I2C device
#
        self.i2c_device = 1 
        self.i2c_device_address = 0x10

#
# Array used to configure the radio
#
        self.Settings = bytearray( 8 )


        self.radio_i2c = I2C( self.i2c_device, scl=self.i2c_scl, sda=self.i2c_sda, freq=200000)
        self.ProgramRadio()

    def SetVolume( self, NewVolume ):
#
# Convert the string into a integer
#
        try:
            NewVolume = int( NewVolume )
            
        except:
            return( False )
        
#
# Validate the type and range check the volume
#
        if ( not isinstance( NewVolume, int )):
            return( False )
        
        if (( NewVolume < 0 ) or ( NewVolume >= 16 )):
            return( False )

        self.Volume = NewVolume
        return( True )

    def SetFrequency( self, NewFrequency ):
#
# Convert the string into a floating point value
#
        try:
            NewFrequency = float( NewFrequency )
            
        except:
            return( False )
#
# validate the type and range check the frequency
#
        if ( not ( isinstance( NewFrequency, float ))):
            return( False )
 
        if (( NewFrequency < 88.0 ) or ( NewFrequency > 108.0 )):
            return( False )

        self.Frequency = NewFrequency
        return( True )

    def SetMute( self, NewMute ):
        
        try:
            self.Mute = bool( int( NewMute ))
            
        except:
            return( False )
        
        return( True )
    
#
# convert the frequency to 10 bit value for the radio chip
#
    def ComputeChannelSetting( self, Frequency ):
        Frequency = int( Frequency * 10 ) - 870
        
        ByteCode = bytearray( 2 )
#
# split the 10 bits into 2 bytes
#
        ByteCode[0] = ( Frequency >> 2 ) & 0xFF
        ByteCode[1] = (( Frequency & 0x03 ) << 6 ) & 0xC0
        return( ByteCode )

#
# Configure the settings array with the mute, frequency and volume settings
#
    def UpdateSettings( self ):
        
        if ( self.Mute ):
            self.Settings[0] = 0x80
        else:
            self.Settings[0] = 0xC0
  
        self.Settings[1] = 0x09 | 0x04
        self.Settings[2:3] = self.ComputeChannelSetting( self.Frequency )
        self.Settings[3] = self.Settings[3] | 0x10
        self.Settings[4] = 0x04
        self.Settings[5] = 0x00
        self.Settings[6] = 0x84
        self.Settings[7] = 0x80 + self.Volume

#        
# Update the settings array and transmitt it to the radio
#
    def ProgramRadio( self ):

        self.UpdateSettings()
        self.radio_i2c.writeto( self.i2c_device_address, self.Settings )

#
# Extract the settings from the radio registers
#
    def GetSettings( self ):
#        
# Need to read the entire register space. This is allow access to the mute and volume settings
# After and address of 255 the 
#
        self.RadioStatus = self.radio_i2c.readfrom( self.i2c_device_address, 256 )

        if (( self.RadioStatus[0xF0] & 0x40 ) != 0x00 ):
            MuteStatus = False
        else:
            MuteStatus = True
            
        VolumeStatus = self.RadioStatus[0xF7] & 0x0F
 
 #
 # Convert the frequency 10 bit count into actual frequency in Mhz
 #
        FrequencyStatus = (( self.RadioStatus[0x00] & 0x03 ) << 8 ) | ( self.RadioStatus[0x01] & 0xFF )
        FrequencyStatus = ( FrequencyStatus * 0.1 ) + 87.0
        
        if (( self.RadioStatus[0x00] & 0x04 ) != 0x00 ):
            StereoStatus = True
        else:
            StereoStatus = False
        
        return( MuteStatus, VolumeStatus, FrequencyStatus, StereoStatus )

    def GetRDS(self):
         #Try and pull the RDS data from the radio
        try:
            # Starting at 0x0A read all bits until 0x3A
            raw_data = self.radio_i2c.readfrom(self.i2c_device_address, 32)
        except:
            return ("", "")
        
        # Make the 16 bit blocks for RDSA - D
        blocks = [
            (raw_data[4] << 8) | raw_data[5],   
            (raw_data[6] << 8) | raw_data[7],   
            (raw_data[8] << 8) | raw_data[9],   
            (raw_data[10] << 8) | raw_data[11]  
        ]

        #Find the group type from block 2 which holds
        group_type = (blocks[1] >> 12) & 0xF
        #Find the program service index which tells where to put station name
        program_service_index = blocks[1] & 0x03

        # If the buffers are not initialized, create them
        if not hasattr(self, "rds_station_buf"):
            self.rds_station_buf = [' '] * 8 # Buffer for station name
            self.rds_station_name_list = [False] * 4 #Buffer for index recieved tracking
        if not hasattr(self, "rds_track_name_buf"):
            self.rds_track_name_buf = [' '] * 64 # Buffer for track name
            self.rds_track_name_segments = [False] * 16 # Track if we have a full track name
        
        index_map = {
            0: (0, 1),
            1: (2, 3),
            2: (4, 5),
            3: (6, 7)
        }

        rds_station_name = ""
        # If group type is 0, we are getting the program service name
        if group_type == 0:
            #Block 3 holds station name characters and we will extract one from each index at a time
            station_chars = [(blocks[3] >> 8) & 0xFF, blocks[3] & 0xFF]
            for buf_idx, char_code in zip(index_map[program_service_index], station_chars):
                if 32 <= char_code <= 126:
                    self.rds_station_buf[buf_idx] = chr(char_code)
                else:
                    self.rds_station_buf[buf_idx] = ' '
            self.rds_station_name_list[program_service_index] = True #Mark as seen
            #If we have seen all 4 indices, make the station name
            if all(self.rds_station_name_list):
                rds_station_name = "".join(self.rds_station_buf).strip()
            else:
                rds_station_name = ""

        rds_song_name = ""
        if group_type == 2:
            song_name_index = (blocks[1] & 0x0F) * 4
            chars = [
                (blocks[2] >> 8) & 0xFF,
                blocks[2] & 0xFF,
                (blocks[3] >> 8) & 0xFF,
                blocks[3] & 0xFF
            ]
            for i in range(4):
                # Assemble the song name in the buffer
                if song_name_index + i < 64:
                    char_code = chars[i]
                    if 32 <= char_code <= 126:
                        self.rds_track_name_buf[song_name_index + i] = chr(char_code)
                    else:
                        self.rds_track_name_buf[song_name_index + i] = ' '
            # Only assemble if all segments received:
            if all(self.rds_track_name_segments):
                rds_song_name = "".join(self.rds_track_name_buf).strip()
            else:
                rds_song_name = ""
        else:
            if hasattr(self, "rds_track_name_buf") and self.rds_track_name_segments:
                rds_song_name = "".join(self.rds_track_name_buf).strip()

        return (rds_station_name, rds_song_name)

#
# initialize the FM radio
#
fm_radio = Radio( 101.9, 2, False )

# Initialize Buttons
button_sw1 = Pin(0, Pin.IN, Pin.PULL_DOWN)  # Rotary Encoder Switch 1
button_sw2 = Pin(3, Pin.IN, Pin.PULL_DOWN)  # Left Button
button_sw3 = Pin(7, Pin.IN, Pin.PULL_DOWN)  # Right Button
button_sw4 = Pin(13, Pin.IN, Pin.PULL_DOWN)  # Rotary Encoder Switch 2

#Rotary Encoders
# Initialize the rotary encoder
# pin_num_dt: Data pin, pin_num_clk: Clock pin
# min_val, max_val: Set a range if needed, otherwise use RANGE_UNBOUNDED
# reverse: Set to True if rotation direction is inverted

# Initialize Rotary Encoders
rotary1 = RotaryIRQ(pin_num_dt=1, pin_num_clk=2,
                    min_val=0, max_val=15.0, reverse=False,
                    range_mode=RotaryIRQ.RANGE_WRAP,
                    pull_up=True)

# Set up rotary2 for frequency selection: 0 to 99 steps (for 88.1 to 107.9)
rotary2 = RotaryIRQ(pin_num_dt=14, pin_num_clk=15,
                    min_val=1, max_val=99, reverse=False,
                    range_mode=RotaryIRQ.RANGE_WRAP,
                    pull_up=True)

r1_old = rotary1.value()
r2_old = rotary2.value()

# FSM for button checking
prevButton = 0
curButton = 0

# Time settings
current_hour = 12
current_minute = 0
is_24_hour_format = True

# Alarm variables
alarm_hour = None
alarm_minute = None
alarm_enabled = False
alarm_triggered = False
alarm_snoozed_until = None
alarm_snooze_count = 0

rtc = RTC()
# Set the RTC to your initial time (only once, or when user sets time)
rtc.datetime((2025, 7, 31, 0, 12, 0, 0, 0))  # (year, month, day, weekday, hour, minute, second, microsecond)

#OLED setup
# OLED display resolution
SCREEN_WIDTH = 128
SCREEN_HEIGHT = 64

# OLED pin setup
spi_sck = Pin(18)
spi_sda = Pin(19)
spi_res = Pin(21)
spi_dc  = Pin(20)
spi_cs  = Pin(17)

SPI_DEVICE = 0

# Initialize SPI and OLED
oled_spi = SPI(SPI_DEVICE, baudrate=100000, sck=spi_sck, mosi=spi_sda)
oled = SSD1306_SPI(SCREEN_WIDTH, SCREEN_HEIGHT, oled_spi, spi_dc, spi_res, spi_cs, True)

last_tick = time.ticks_ms()
last_menu_print = time.ticks_ms()

last_station_name = ""
last_freq = fm_radio.Frequency

scroll_index = 0
scroll_last_update = time.ticks_ms()
SCROLL_INTERVAL = 250

while True:
    last_tick = time.ticks_ms()
    select = None

    # Main menu display and button wait
    while True:
        # Update time display every second
        if time.ticks_diff(time.ticks_ms(), last_tick) >= 1000:
            now = rtc.datetime()
            current_hour = now[4]
            current_minute = now[5]
            current_second = now[6]

            # Format time string based on 12/24hr setting
            if is_24_hour_format:
                time_str = "%02d:%02d:%02d" % (current_hour, current_minute, current_second)
            else:
                hour_12 = current_hour % 12
                if hour_12 == 0:
                    hour_12 = 12
                am_pm_display = "AM" if current_hour < 12 else "PM"
                time_str = "%02d:%02d:%02d %s" % (hour_12, current_minute, current_second, am_pm_display)

            # Get RDS info
            new_station_name, new_song_title = fm_radio.GetRDS()

            # Only update if new full data arrives
            if new_station_name.strip() and new_station_name != last_station_name:
                last_station_name = new_station_name
                station_scroll_index = 0
                station_scroll_last_update = time.ticks_ms()
            if new_song_title.strip():
                song_title = new_song_title
                scroll_index = 0
                scroll_last_update = time.ticks_ms()

            # If frequency changed, clear PS buffer and update last_freq
            if fm_radio.Frequency != last_freq:
                if hasattr(fm_radio, "rds_station_buf"):
                    fm_radio.rds_station_buf = [' '] * 8
                last_freq = fm_radio.Frequency
                station_name = ""  # Force blank until new RDS arrives

            # Only show frequency if no RDS station name
            if not last_station_name or last_station_name.strip() == "":
                display_text = "%.1f MHz" % fm_radio.Frequency
            else:
                display_text = last_station_name


            # OLED main info display
            oled.fill(0)
            oled.text(time_str, 0, 0)  # Line 1: Time at the top
            oled.text("%.1f MHz" % fm_radio.Frequency, 0, 16) # Line 2: Frequency display

            # RDS RadioText scrolling display (Line 3)
            display_width = 16
            if 'song_title' not in locals():
                song_title = ""
            if len(song_title) > display_width:
                if time.ticks_diff(time.ticks_ms(), scroll_last_update) > SCROLL_INTERVAL:
                    scroll_index = (scroll_index + 1) % (len(song_title) - display_width + 1)
                    scroll_last_update = time.ticks_ms()
                scroll_text = song_title[scroll_index:scroll_index + display_width]
            else:
                scroll_text = song_title
                scroll_index = 0
                scroll_last_update = time.ticks_ms()
            oled.text(scroll_text, 0, 32)  # Line 3: RDS RadioText

            oled.text("Vol:%d" % fm_radio.Volume, 0, 50)   # Volume in corner
            oled.show()

            last_tick = time.ticks_ms()

        # Print menu to console once per second
        if time.ticks_diff(time.ticks_ms(), last_menu_print) >= 1000:
            # If the time string is set, print it
            print("Current time:", time_str if 'time_str' in locals() else "Loading...")
            print("")
            print("ECE 299 FM Radio Demo Menu")
            print("Press SW1 for: change volume level")
            print("Press SW2 for: change between 12/24hr time")
            print("Press SW3 for: set alarm")
            print("Press SW4 for: change radio frequency")
            print("")
            # Print RDS info to console
            print("RDS Station Name:", last_station_name if last_station_name else "(none)")
            print("RDS RadioText:", song_title if 'song_title' in locals() and song_title else "(none)")

            last_menu_print = time.ticks_ms()

            # Alarm trigger check
            if alarm_enabled:
                # If snoozing, wait until snooze expires
                if alarm_snoozed_until is not None:
                    if time.time() < alarm_snoozed_until:
                        # Still snoozing, do nothing
                        pass
                    else:
                        # Snooze expired
                        alarm_snoozed_until = None
                        alarm_triggered = False  # Allow retrigger
                # If not snoozing and alarm time has passed, trigger alarm
                elif (
                    not alarm_triggered and
                    (
                        (current_hour > alarm_hour) or
                        (current_hour == alarm_hour and current_minute >= alarm_minute)
                    )
                ):
                    print("Alarm! Turning radio on at max volume.")
                    fm_radio.SetMute(False)
                    fm_radio.SetVolume(15)
                    fm_radio.ProgramRadio()
                    alarm_triggered = True

                    # OLED alarm display and snooze/cancel handling
                    alarm_active = True
                    while alarm_active:
                        oled.fill(0)
                        oled.text("ALARM GOING OFF!", 5, 10)
                        oled.text("SW4: Snooze", 10, 30)
                        oled.text("SW1: Cancel", 10, 45)
                        oled.show()

                        # Snooze (SW4)
                        if button_sw4.value():
                            print("Alarm snoozed for 30 seconds.")
                            alarm_snoozed_until = time.time() + 15
                            alarm_active = False
                            alarm_triggered = False  # Allow retrigger after snooze
                            time.sleep(0.5)  # debounce
                            break

                        # Cancel (SW1)
                        if button_sw1.value():
                            print("Alarm cancelled.")
                            alarm_enabled = False
                            alarm_triggered = False
                            alarm_active = False
                            alarm_snoozed_until = None
                            time.sleep(0.5)  # debounce
                            break

                        time.sleep_ms(50)
            
            if fm_radio.Frequency != last_freq:
                # Reset RDS buffers
                if hasattr(fm_radio, "rds_station_buf"):
                    fm_radio.rds_station_buf = [' '] * 8
                    fm_radio.rds_ps_received = [False] * 4
                if hasattr(fm_radio, "rds_track_name_buf"):
                    fm_radio.rds_track_name_buf = [' '] * 64
                last_freq = fm_radio.Frequency
                station_name = ""


        if button_sw1.value():
            select = "1"
            break
        elif button_sw2.value():
            select = "2"
            break
        elif button_sw3.value():
            select = "3"
            break
        elif button_sw4.value():
            select = "4"
            break
        time.sleep_ms(50)

    # Debounce: wait for button release
    while (button_sw1.value() == 1 or button_sw2.value() == 1 or
           button_sw3.value() == 1 or button_sw4.value() == 1):
        time.sleep(0.05)

#
# Set volume level of radio
#
    # Menu selection handling
    if select == "1":
        print("Rotate rotary1 to change volume.")
        print("Press Button SW1 (Pin 0) to confirm and return to menu.")
        val_old = rotary1.value()
        
        while True:
            val_new = rotary1.value()
            
            # Only update display when rotary changes
            if val_new != val_old:
                val_old = val_new
                print("Volume:", val_new)
                time.sleep_ms(50) # debounce delay

            # OLED live update for volume
            oled.fill(0)
            oled.text("Set Volume", 10, 0)
            oled.text("Volume: %d" % val_old, 10, 10)
            if val_old == 0:
                oled.text("(Muted)", 10, 25)
            oled.text("SW1: Confirm", 10, 40)
            oled.text("SW4: Cancel", 10, 50)
            oled.show()

            # Only program the radio when button is pressed
            if button_sw1.value() == 1:
                # Apply the volume setting to the radio
                if val_old == 0:
                    fm_radio.SetMute(True)
                else:
                    fm_radio.SetMute(False)
                
                if fm_radio.SetVolume(val_old):
                    fm_radio.ProgramRadio()
                    print("Volume set to:", val_old)
                    print("Returning to menu...")
                else:
                    print("Error setting volume")
                
                time.sleep(0.5)  # debounce delay
                break

            # Cancel and return to menu when SW4 is pressed
            if button_sw4.value() == 1:
                print("Volume selection cancelled. Returning to menu...")
                time.sleep(0.5)  # debounce delay
                break
            
            time.sleep_ms(50)  # Main loop delay
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

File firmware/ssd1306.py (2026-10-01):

# MicroPython SSD1306 OLED driver, I2C and SPI interfaces

from micropython import const
import framebuf


# register definitions
SET_CONTRAST = const(0x81)
SET_ENTIRE_ON = const(0xA4)
SET_NORM_INV = const(0xA6)
SET_DISP = const(0xAE)
SET_MEM_ADDR = const(0x20)
SET_COL_ADDR = const(0x21)
SET_PAGE_ADDR = const(0x22)
SET_DISP_START_LINE = const(0x40)
SET_SEG_REMAP = const(0xA0)
SET_MUX_RATIO = const(0xA8)
SET_IREF_SELECT = const(0xAD)
SET_COM_OUT_DIR = const(0xC0)
SET_DISP_OFFSET = const(0xD3)
SET_COM_PIN_CFG = const(0xDA)
SET_DISP_CLK_DIV = const(0xD5)
SET_PRECHARGE = const(0xD9)
SET_VCOM_DESEL = const(0xDB)
SET_CHARGE_PUMP = const(0x8D)

# Subclassing FrameBuffer provides support for graphics primitives
# http://docs.micropython.org/en/latest/pyboard/library/framebuf.html
class SSD1306(framebuf.FrameBuffer):
    def __init__(self, width, height, external_vcc):
        self.width = width
        self.height = height
        self.external_vcc = external_vcc
        self.pages = self.height // 8
        self.buffer = bytearray(self.pages * self.width)
        super().__init__(self.buffer, self.width, self.height, framebuf.MONO_VLSB)
        self.init_display()

    def init_display(self):
        for cmd in (
            SET_DISP,  # display off
            # address setting
            SET_MEM_ADDR,
            0x00,  # horizontal
            # resolution and layout
            SET_DISP_START_LINE,  # start at line 0
            SET_SEG_REMAP | 0x01,  # column addr 127 mapped to SEG0
            SET_MUX_RATIO,
            self.height - 1,
            SET_COM_OUT_DIR | 0x08,  # scan from COM[N] to COM0
            SET_DISP_OFFSET,
            0x00,
            SET_COM_PIN_CFG,
            0x02 if self.width > 2 * self.height else 0x12,
            # timing and driving scheme
            SET_DISP_CLK_DIV,
            0x80,
            SET_PRECHARGE,
            0x22 if self.external_vcc else 0xF1,
            SET_VCOM_DESEL,
            0x30,  # 0.83*Vcc
            # display
            SET_CONTRAST,
            0xFF,  # maximum
            SET_ENTIRE_ON,  # output follows RAM contents
            SET_NORM_INV,  # not inverted
            SET_IREF_SELECT,
            0x30,  # enable internal IREF during display on
            # charge pump
            SET_CHARGE_PUMP,
            0x10 if self.external_vcc else 0x14,
            SET_DISP | 0x01,  # display on
        ):  # on
            self.write_cmd(cmd)
        self.fill(0)
        self.show()

    def poweroff(self):
        self.write_cmd(SET_DISP)

    def poweron(self):
        self.write_cmd(SET_DISP | 0x01)

    def contrast(self, contrast):
        self.write_cmd(SET_CONTRAST)
        self.write_cmd(contrast)

    def invert(self, invert):
        self.write_cmd(SET_NORM_INV | (invert & 1))

    def rotate(self, rotate):
        self.write_cmd(SET_COM_OUT_DIR | ((rotate & 1) << 3))
        self.write_cmd(SET_SEG_REMAP | (rotate & 1))

    def show(self):
        for Page in range( 0, 8 ):
            self.write_cmd( 0xB0 | ( Page & 0x0F ))
            self.write_cmd( 0x02 )
            self.write_cmd( 0x10 )
            self.write_data( self.buffer[Page<<7:(Page<<7)+128] )


class SSD1306_I2C(SSD1306):
    def __init__(self, width, height, i2c, addr=0x3C, external_vcc=False):
        self.i2c = i2c
        self.addr = addr
        self.temp = bytearray(2)
        self.write_list = [b"\x40", None]  # Co=0, D/C#=1
        super().__init__(width, height, external_vcc)

    def write_cmd(self, cmd):
        self.temp[0] = 0x80  # Co=1, D/C#=0
        self.temp[1] = cmd
        self.i2c.writeto(self.addr, self.temp)

    def write_data(self, buf):
        Page = 0
        
        for Page in range( 0, 8 ):
            self.i2c.writeto_mem( 0x3C, 0x80, ( 0xB0 | ( Page & 0x0F ) ).to_bytes(1, 0 ))
            self.i2c.writeto_mem( 0x3C, 0x80, b'\x02' )
            self.i2c.writeto_mem( 0x3C, 0x80, b'\x10' )
            buf1 = buf[Page<<7:(Page<<7)+128]
            self.write_list[1] = buf1
            
            self.i2c.writevto( 0x3C, self.write_list )

class SSD1306_SPI(SSD1306):
    def __init__(self, width, height, spi, dc, res, cs, external_vcc=False):
        self.rate = 10 * 1024 * 1024
        dc.init(dc.OUT, value=0)
        res.init(res.OUT, value=0)
        cs.init(cs.OUT, value=1)
        self.spi = spi
        self.dc = dc
        self.res = res
        self.cs = cs
        import time

        self.res(1)
        time.sleep_ms(1)
        self.res(0)
        time.sleep_ms(10)
        self.res(1)
        super().__init__(width, height, external_vcc)

    def write_cmd(self, cmd):
        self.spi.init(baudrate=self.rate, polarity=0, phase=0)
        self.cs(1)
        self.dc(0)
        self.cs(0)
        self.spi.write(bytearray([cmd]))
        self.cs(1)

    def write_data(self, buf):
        self.spi.init(baudrate=self.rate, polarity=0, phase=0)
        self.cs(1)
        self.dc(1)
        self.cs(0)
        self.spi.write(buf)
        self.cs(1)
            

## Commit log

2026-10-01 Add project folder structure
    [Animal.SLDPRT, Back part.SLDPRT, Enclosure drawing.SLDDRW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]
2026-10-01 Fixed schematic image
